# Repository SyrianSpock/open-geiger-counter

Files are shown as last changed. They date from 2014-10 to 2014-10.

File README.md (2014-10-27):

open-geiger-counter
===================

Description
-----------

The <a href="http://opengeiger.de/index_en.html">Open geiger</a> project aims to give access to cheap geiger counters for the masses.
This is an attempt at making such a cheap geiger counter - using PIN diodes and following the design of the 'Stuttgarter Geigerle'- in a smaller size form.
In this repository are made available the production files for the realisation of such a cheap pocket geiger counter:
  * <a href="open-geiger-counter/schematic.pdf">Schematic</a>
  * <a href="open-geiger-counter/kicad">Kicad files</a>
  * <a href="open-geiger-counter/gerber">Gerber files</a>
  * 3D printed case (TBD)

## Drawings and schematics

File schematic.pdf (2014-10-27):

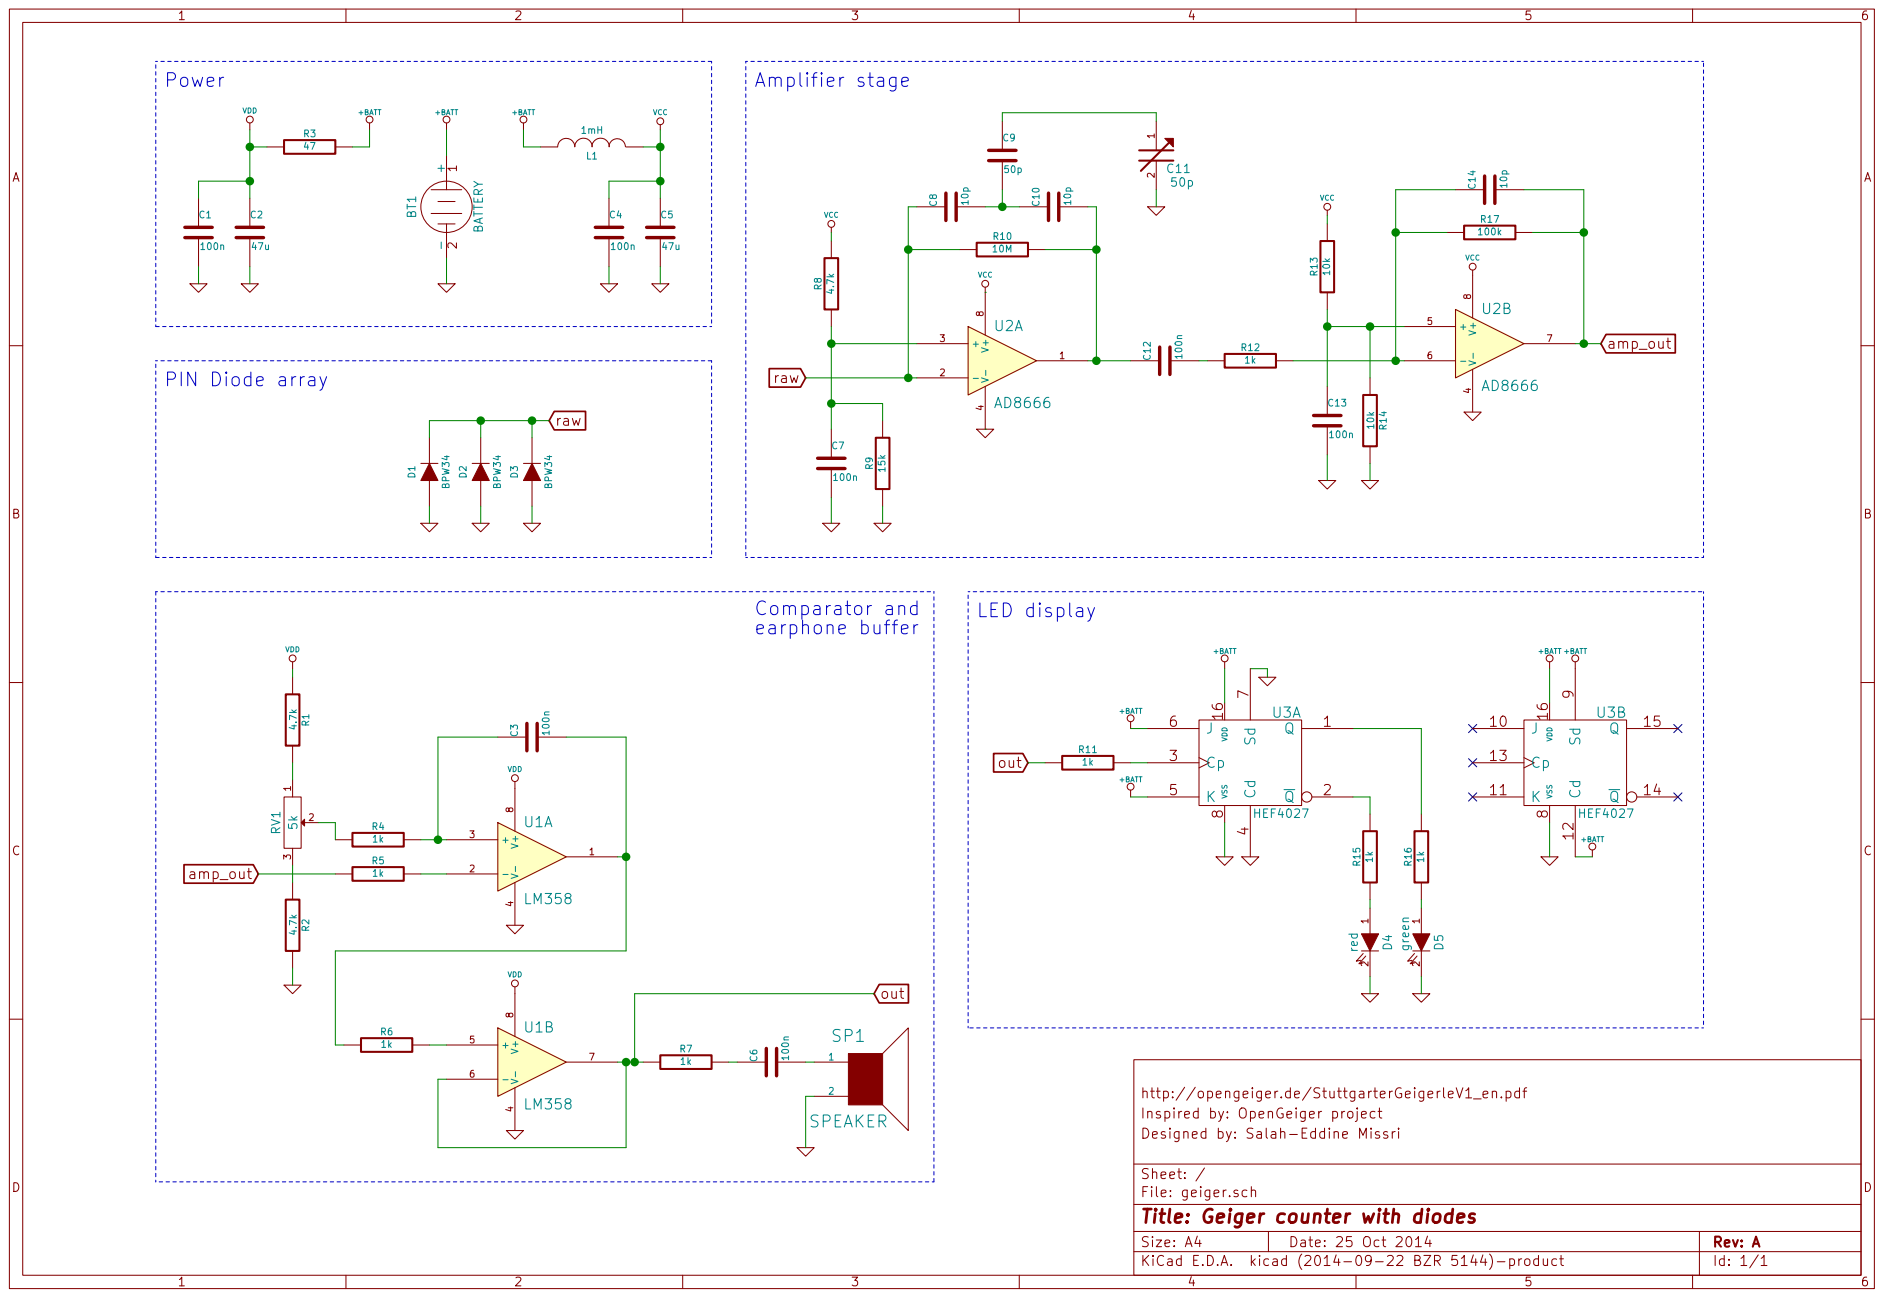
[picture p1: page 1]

Inspired by: OpenGeiger project
File: geiger.sch Sheet: / Designed by: Salah-Eddine Missri

Id: 1/1 Title: Geiger counter with diodes

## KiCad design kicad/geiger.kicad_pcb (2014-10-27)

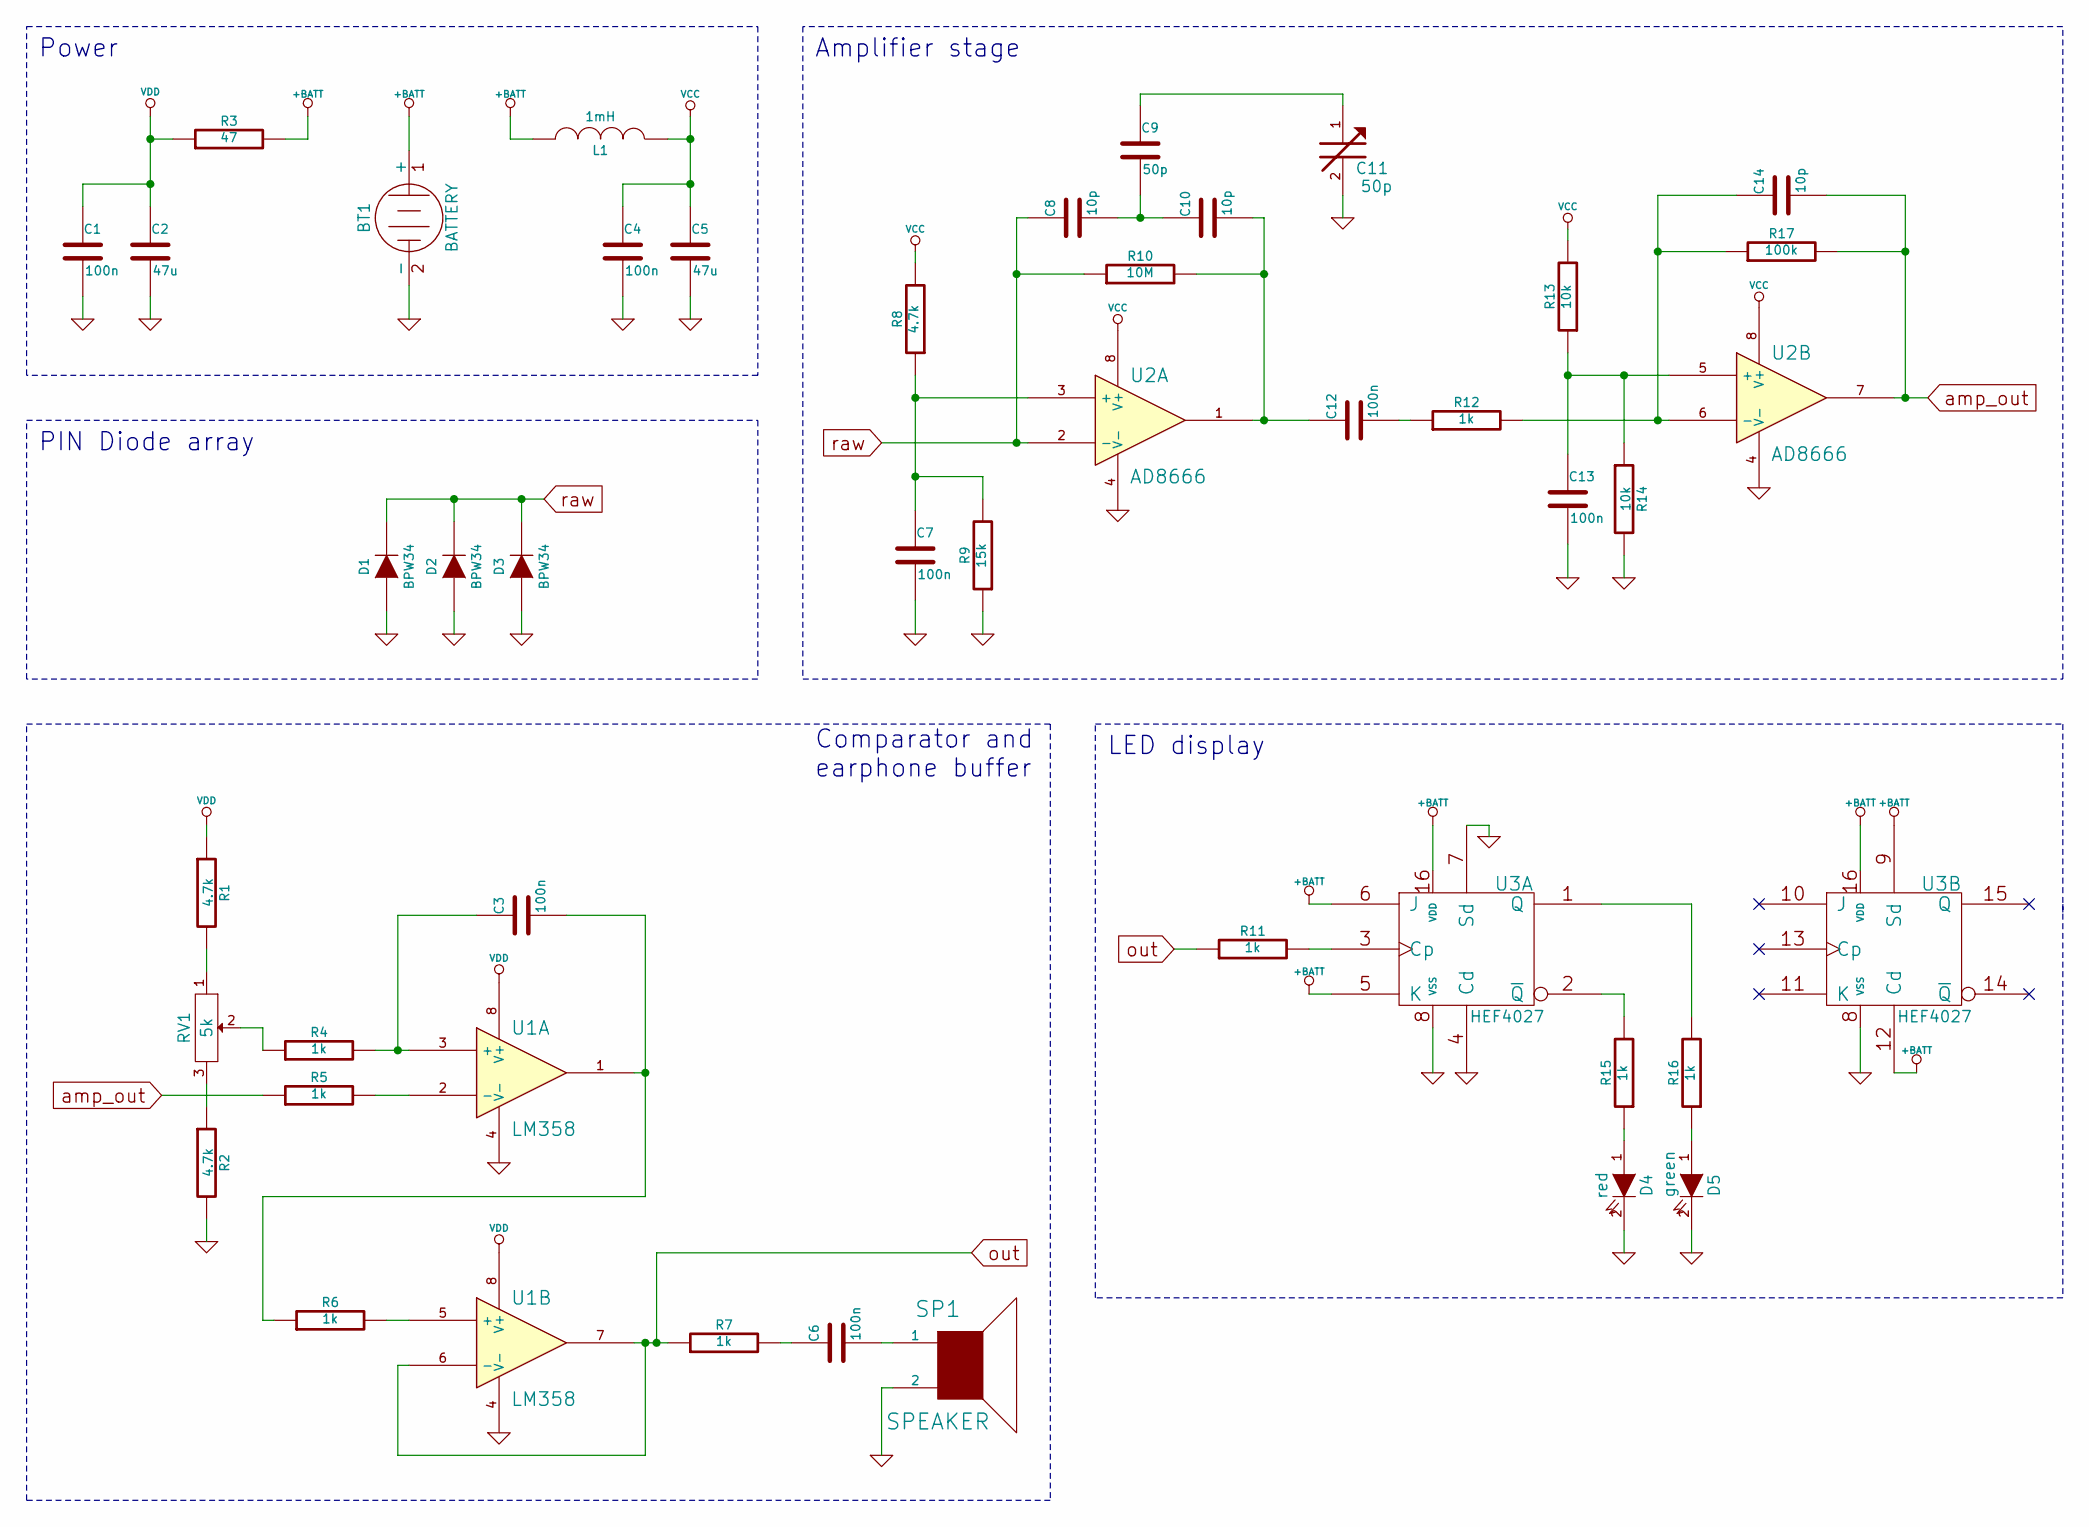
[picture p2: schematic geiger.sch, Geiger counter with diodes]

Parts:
BT1: BATTERY
C1, C3, C4, C6, C7, C12, C13: 100n
C2, C5: 47u
C8, C10, C14: 10p
C9, C11: 50p
D1, D2, D3: BPW34
D4: red
D5: green
L1: 1mH
R1, R2, R8: 4.7k
R3: 47
R4, R5, R6, R7, R11, R12, R15, R16: 1k
R9: 15k
R10: 10M
R13, R14: 10k
R17: 100k
RV1: 5k
SP1: SPEAKER
U1: LM358
U2: AD8666
U3: HEF4027

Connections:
+BATT: BT1.1 (+), L1.2, R3.2, U3.5 (K), U3.6 (J), U3.9 (Sd), U3.12 (Cd), U3.16 (VDD)
GND: BT1.2 (-), C1.2, C2.2, C4.2, C5.2, C7.2, C11.2, C13.2, D1.1 (A), D2.1 (A), D3.1 (A), D4.2 (K), D5.2 (K), R2.2, R9.1, R14.2, SP1.2, U1.4 (V-), U2.4 (V-), U3.4 (Cd), U3.7 (Sd), U3.8 (VSS)
unnamed: C3.1, R4.2, U1.3 (+)
unnamed: C3.2, R6.1, U1.1
unnamed: C6.1, R7.2
unnamed: C6.2, SP1.1
unnamed: C7.1, R8.1, R9.2, U2.3 (+)
unnamed: C8.2, C9.2, C10.1
unnamed: C10.2, C12.1, R10.2, U2.1
unnamed: C9.1, C11.1
unnamed: C12.2, R12.1
unnamed: C13.1, R13.1, R14.1, U2.5 (+)
unnamed: C14.1, R12.2, R17.1, U2.6 (-)
unnamed: D4.1 (A), R15.1
unnamed: D5.1 (A), R16.1
unnamed: R1.2, RV1.1
unnamed: R2.1, RV1.3
unnamed: R4.1, RV1.2
unnamed: R5.2, U1.2 (-)
unnamed: R6.2, U1.5 (+)
unnamed: R11.2, U3.3 (Cp)
unnamed: R15.2, U3.2 (~Q)
unnamed: R16.2, U3.1 (Q)
VCC: C4.1, C5.1, L1.1, R8.2, R13.2, U2.8 (V+)
VDD: C1.1, C2.1, R1.1, R3.1, U1.8 (V+)
amp_out: C14.2, R5.1, R17.2, U2.7
out: R7.1, R11.1, U1.6 (-), U1.7
raw: C8.1, D1.2 (K), D2.2 (K), D3.2 (K), R10.1, U2.2 (-)

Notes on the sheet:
PIN Diode array
Power
Amplifier stage
Comparator and earphone buffer
LED display

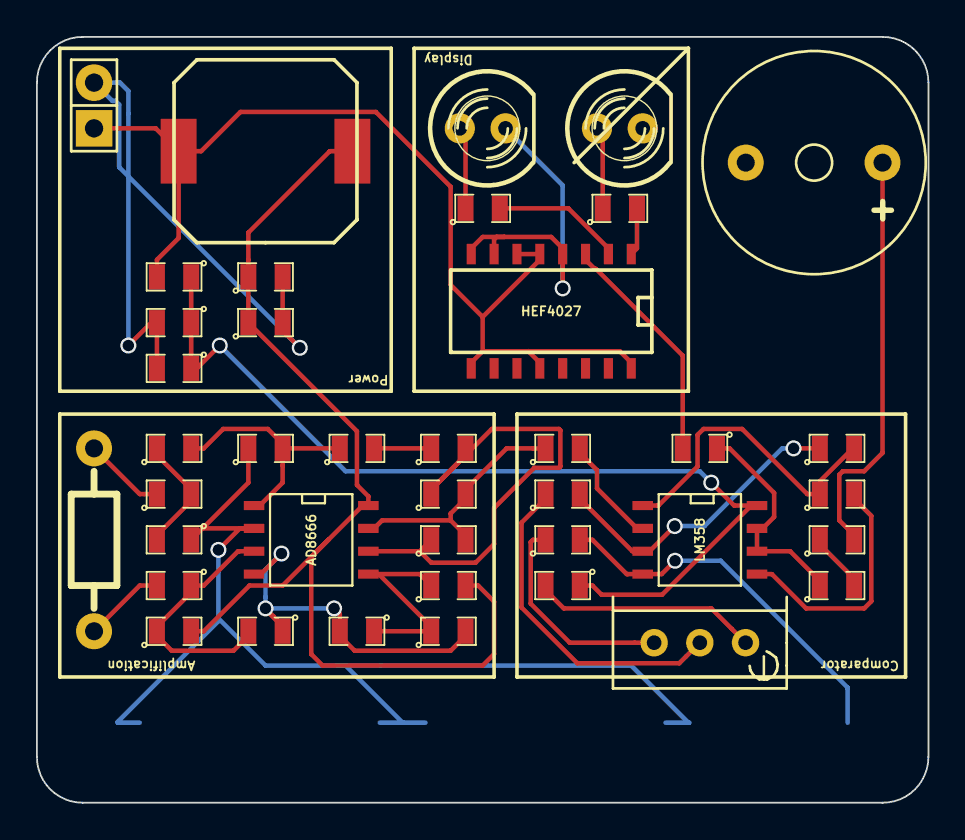
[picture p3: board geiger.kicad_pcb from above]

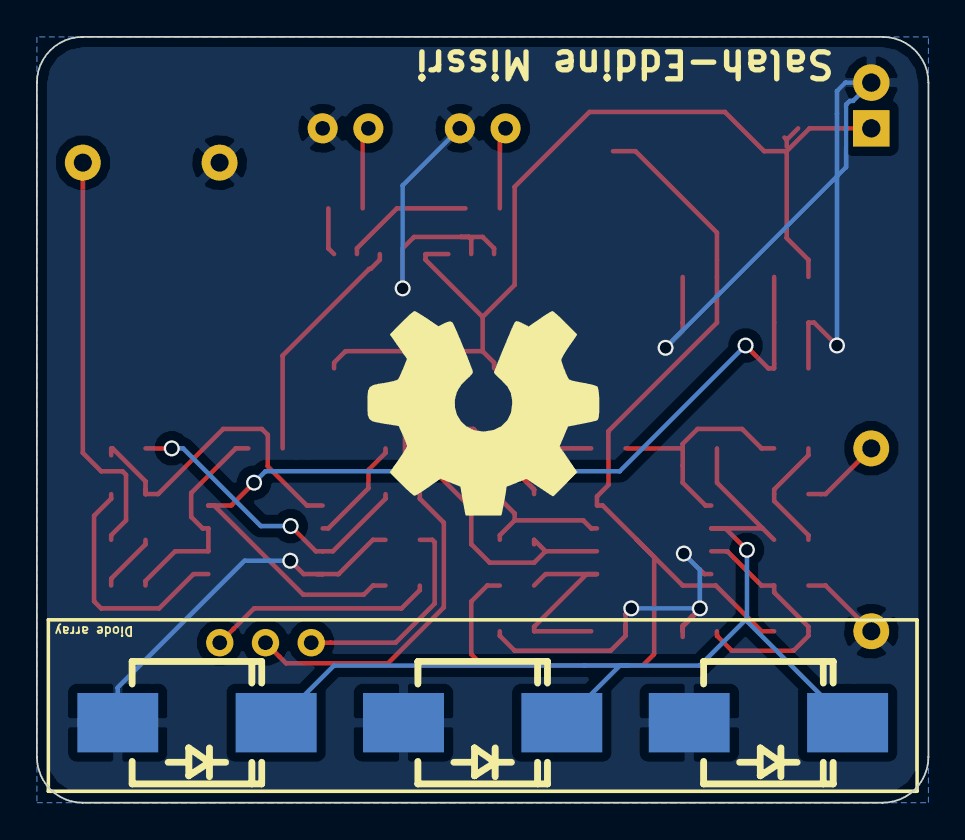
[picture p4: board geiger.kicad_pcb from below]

Board: 2 copper layers, 49.5 x 42.5 mm, 43 parts (3 on the bottom side), 28 nets.
